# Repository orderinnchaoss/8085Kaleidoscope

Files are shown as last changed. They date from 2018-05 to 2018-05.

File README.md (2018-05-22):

# 8085Kaleidoscope Under Professor D.V.Gadre
This contains files 8085 
Includes
1)Schematics and BoardFiles
2)Main Code(Text,Hex,Bin)
3)Report
4)Program Flowchart

Can be reproduced with permission, by the contacts under

Made by 
 Priyanshu Pandey 130/EC/15 - 95608-59659 - priyanshupandey7997@gmail.com / priyanshup.ec@nsit.net.in
 Nishant Arora 110/EC/15 - 78387-67240 - arora.nishant97@gmail.com

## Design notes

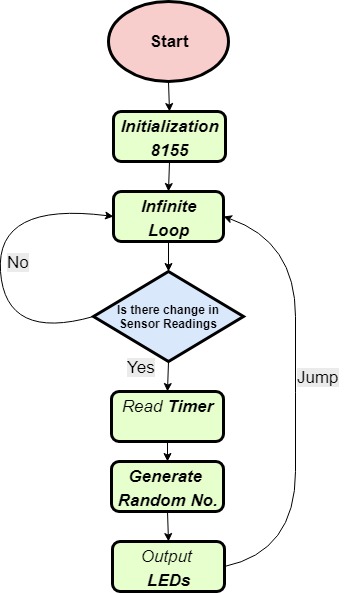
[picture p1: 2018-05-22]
Codeflow.jpg

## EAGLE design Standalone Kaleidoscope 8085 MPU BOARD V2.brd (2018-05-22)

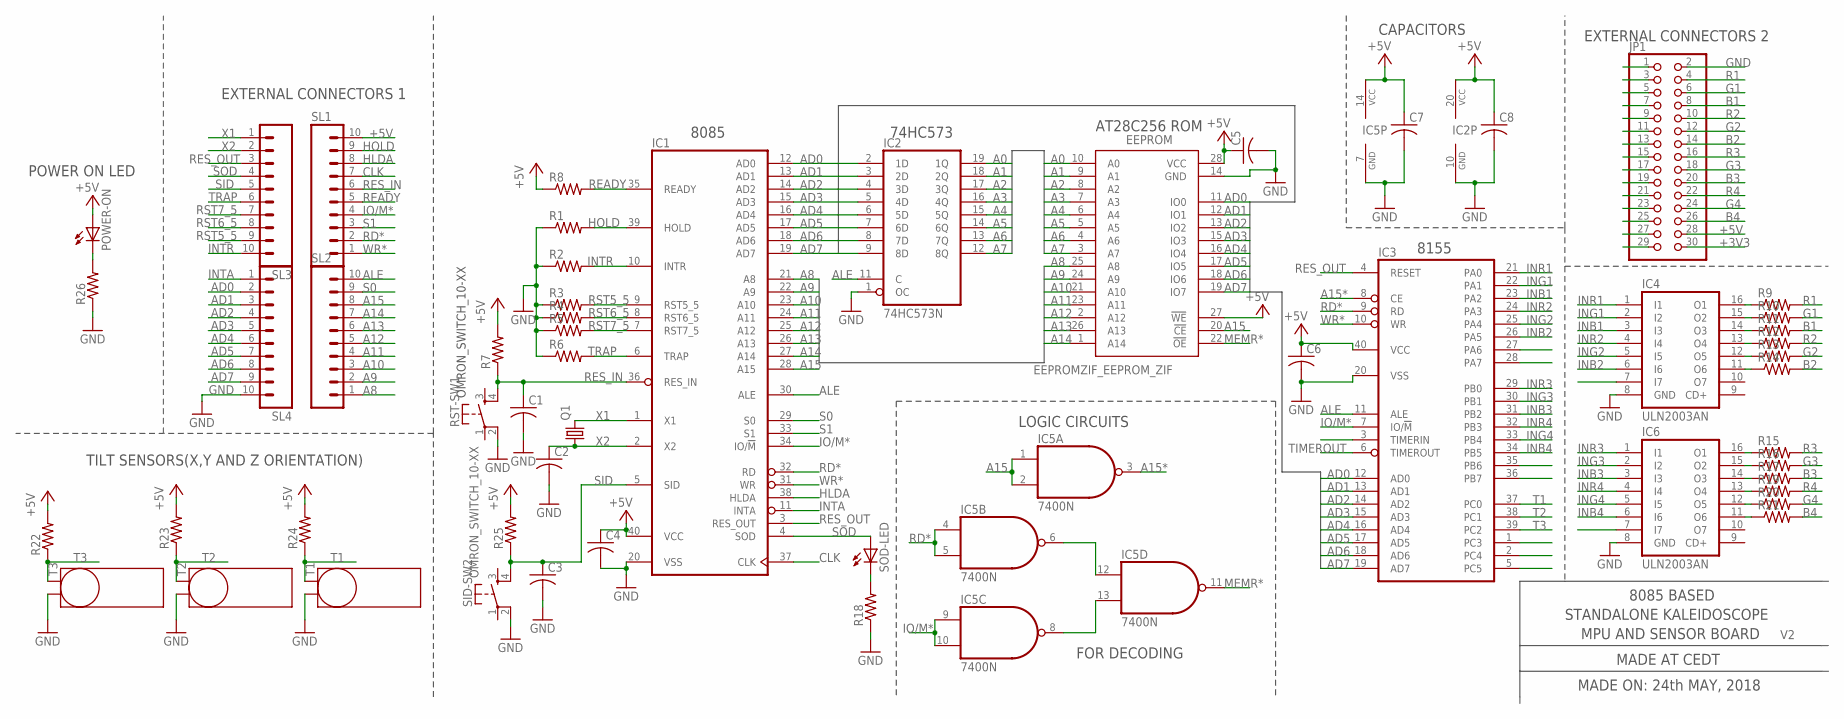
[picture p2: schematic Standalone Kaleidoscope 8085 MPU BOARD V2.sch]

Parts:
C1, C2, C3, C4, C5, C6: C-USC0805K; C0805K
C7, C8: C-USC0805; C0805
EEPROM: EEPROMZIF_EEPROM_ZIF; EEPROMZIF_DIL28-6-ZIF_SOCKET
IC1: 8085; DIL40
IC2: 74HC573N; DIL20
IC3: 8155; DIL40
IC4, IC6: ULN2003AN; DIL16
IC5: 7400N; DIL14
JP1: PINHD-2X15; 2X15
POWER-ON: LEDCHIP-LED0805; CHIP-LED0805
Q1: CEDT_JANUARY_2015_V5_A_CRYSTALHC49US; CEDT_JANUARY_2015_V5_A_HC49US
R1, R2, R3, R4, R5, R6, R7, R8, R9, R10, R11, R12, R13, R14, R15, R16, R17, R18, R19, R20, R21, R22, R23, R24, R25, R26: R-US_R0805; R0805
RST-SW1: OMRON_SWITCH_10-XX; B3F-10XX
SID-SW2: OMRON_SWITCH_10-XX; B3F-10XX
SL1, SL2, SL3, SL4: CON-AMP-QUICK_M10; CON-AMP-QUICK_10P
SOD-LED: LEDCHIP-LED0805; CHIP-LED0805
T1, T2, T3: TILTSENSORE2.5-7; TILTSENSOR

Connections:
+3V3: JP1.29, JP1.30
+5V: C4.1, C5.1, C6.1, C7.1, C8.1, EEPROM.27 (!WE), EEPROM.28 (VCC), IC1.40 (VCC), IC2.20 (VCC), IC3.40 (VCC), IC5.14 (VCC), JP1.27, JP1.28, POWER-ON.A, R7.2, R8.1, R22.2, R23.2, R24.2, R25.2, SL1.10
A0: EEPROM.10 (A0), IC2.19 (1Q)
A1: EEPROM.9 (A1), IC2.18 (2Q)
A2: EEPROM.8 (A2), IC2.17 (3Q)
A3: EEPROM.7 (A3), IC2.16 (4Q)
A4: EEPROM.6 (A4), IC2.15 (5Q)
A5: EEPROM.5 (A5), IC2.14 (6Q)
A6: EEPROM.4 (A6), IC2.13 (7Q)
A7: EEPROM.3 (A7), IC2.12 (8Q)
A8: EEPROM.25 (A8), IC1.21 (A8), SL2.1
A9: EEPROM.24 (A9), IC1.22 (A9), SL2.2
A10: EEPROM.21 (A10), IC1.23 (A10), SL2.3
A11: EEPROM.23 (A11), IC1.24 (A11), SL2.4
A12: EEPROM.2 (A12), IC1.25 (A12), SL2.5
A13: EEPROM.26 (A13), IC1.26 (A13), SL2.6
A14: EEPROM.1 (A14), IC1.27 (A14), SL2.7
A15: EEPROM.20 (!CE), IC1.28 (A15), IC5.1 (I0), IC5.2 (I1), SL2.8
A15*: IC3.8 (CE), IC5.3 (O)
AD0: EEPROM.11 (IO0), IC1.12 (AD0), IC2.2 (1D), IC3.12 (AD0), SL4.2
AD1: EEPROM.12 (IO1), IC1.13 (AD1), IC2.3 (2D), IC3.13 (AD1), SL4.3
AD2: EEPROM.13 (IO2), IC1.14 (AD2), IC2.4 (3D), IC3.14 (AD2), SL4.4
AD3: EEPROM.15 (IO3), IC1.15 (AD3), IC2.5 (4D), IC3.15 (AD3), SL4.5
AD4: EEPROM.16 (IO4), IC1.16 (AD4), IC2.6 (5D), IC3.16 (AD4), SL4.6
AD5: EEPROM.17 (IO5), IC1.17 (AD5), IC2.7 (6D), IC3.17 (AD5), SL4.7
AD6: EEPROM.18 (IO6), IC1.18 (AD6), IC2.8 (7D), IC3.18 (AD6), SL4.8
AD7: EEPROM.19 (IO7), IC1.19 (AD7), IC2.9 (8D), IC3.19 (AD7), SL4.9
ALE: IC1.30 (ALE), IC2.11 (C), IC3.11 (ALE), SL2.10
B1: JP1.7, JP1.8, R11.2
B2: JP1.13, JP1.14, R14.2
B3: JP1.19, JP1.20, R17.2
B4: JP1.25, JP1.26, R21.2
CLK: IC1.37 (CLK), SL1.7
G1: JP1.5, JP1.6, R10.2
G2: JP1.11, JP1.12, R13.2
G3: JP1.17, JP1.18, R16.2
G4: JP1.23, JP1.24, R20.2
GND: C1.2, C2.2, C3.2, C4.2, C5.2, C6.2, C7.2, C8.2, EEPROM.14 (GND), IC1.20 (VSS), IC2.1 (OC), IC2.10 (GND), IC3.20 (VSS), IC4.8 (GND), IC5.7 (GND), IC6.8 (GND), JP1.1, JP1.2, R1.1, R2.1, R3.1, R4.1, R5.1, R6.1, R18.1, R26.1, RST-SW1.2 (P1), SID-SW2.2 (P1), SL4.10, T1.-, T2.-, T3.-
HLDA: IC1.38 (HLDA), SL1.8
HOLD: IC1.39 (HOLD), R1.2, SL1.9
INB1: IC3.23 (PA2), IC4.3 (I3)
INB2: IC3.26 (PA5), IC4.6 (I6)
INB3: IC3.31 (PB2), IC6.3 (I3)
INB4: IC3.34 (PB5), IC6.6 (I6)
ING1: IC3.22 (PA1), IC4.2 (I2)
ING2: IC3.25 (PA4), IC4.5 (I5)
ING3: IC3.30 (PB1), IC6.2 (I2)
ING4: IC3.33 (PB4), IC6.5 (I5)
INR1: IC3.21 (PA0), IC4.1 (I1)
INR2: IC3.24 (PA3), IC4.4 (I4)
INR3: IC3.29 (PB0), IC6.1 (I1)
INR4: IC3.32 (PB3), IC6.4 (I4)
INTA: IC1.11 (INTA), SL4.1
INTR: IC1.10 (INTR), R2.2, SL3.10
IO/M*: IC1.34 (IO/!M), IC3.7 (IO/!M), IC5.9 (I0), IC5.10 (I1), SL1.4
MEMR*: EEPROM.22 (!OE), IC5.11 (O)
unnamed: POWER-ON.C, R26.2
unnamed: IC4.16 (O1), R9.1
unnamed: IC4.15 (O2), R10.1
unnamed: IC4.14 (O3), R11.1
unnamed: IC5.6 (O), IC5.12 (I0)
unnamed: IC5.8 (O), IC5.13 (I1)
unnamed: IC4.13 (O4), R12.1
unnamed: IC4.12 (O5), R13.1
unnamed: IC4.11 (O6), R14.1
unnamed: IC6.11 (O6), R21.1
unnamed: IC6.12 (O5), R20.1
unnamed: IC6.13 (O4), R19.1
unnamed: IC6.14 (O3), R17.1
unnamed: IC6.15 (O2), R16.1
unnamed: R18.2, SOD-LED.C
unnamed: IC6.16 (O1), R15.1
R1: JP1.3, JP1.4, R9.2
R2: JP1.9, JP1.10, R12.2
R3: JP1.15, JP1.16, R15.2
R4: JP1.21, JP1.22, R19.2
RD*: IC1.32 (RD), IC3.9 (RD), IC5.4 (I0), IC5.5 (I1), SL1.2
READY: IC1.35 (READY), R8.2, SL1.5
RES_IN: C1.1, IC1.36 (RES_IN), R7.1, RST-SW1.4 (S1), SL1.6
RES_OUT: IC1.3 (RES_OUT), IC3.4 (RESET), SL3.3
RST5_5: IC1.9 (RST5_5), R3.2, SL3.9
RST6_5: IC1.8 (RST6_5), R4.2, SL3.8
RST7_5: IC1.7 (RST7_5), R5.2, SL3.7
S0: IC1.29 (S0), SL2.9
S1: IC1.33 (S1), SL1.3
SID: C3.1, IC1.5 (SID), R25.1, SID-SW2.4 (S1), SL3.5
SOD: IC1.4 (SOD), SL3.4, SOD-LED.A
T1: IC3.37 (PC0), R24.1, T1.+
T2: IC3.38 (PC1), R23.1, T2.+
T3: IC3.39 (PC2), R22.1, T3.+
TIMEROUT: IC3.6 (TIMEROUT)
TRAP: IC1.6 (TRAP), R6.2, SL3.6
WR*: IC1.31 (WR), IC3.10 (WR), SL1.1
X1: IC1.1 (X1), Q1.2, SL3.1
X2: C2.1, IC1.2 (X2), Q1.1, SL3.2

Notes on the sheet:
TILT SENSORS(X,Y AND Z ORIENTATION)
8085
74HC573
AT28C256 ROM
CAPACITORS
8155
EXTERNAL CONNECTORS 2
EXTERNAL CONNECTORS 1
LOGIC CIRCUITS
POWER ON LED
8085 BASED
STANDALONE KALEIDOSCOPE
MADE AT CEDT
MPU AND SENSOR BOARD
MADE ON: 24th MAY, 2018
FOR DECODING

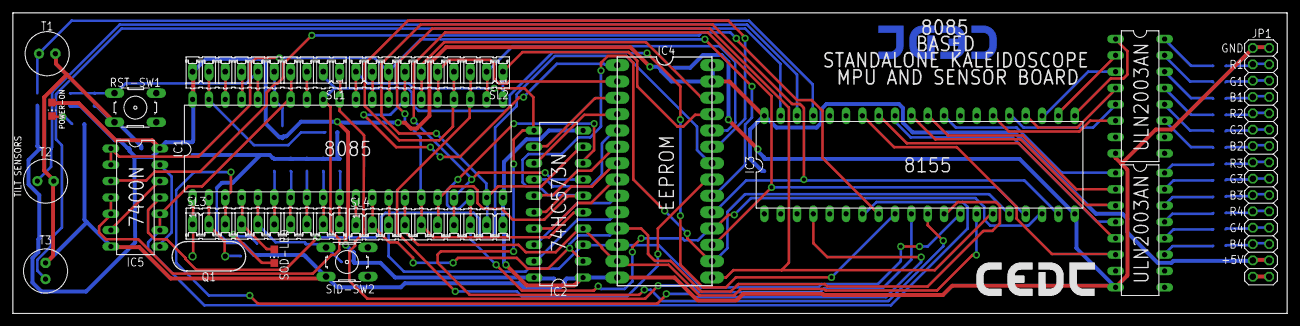
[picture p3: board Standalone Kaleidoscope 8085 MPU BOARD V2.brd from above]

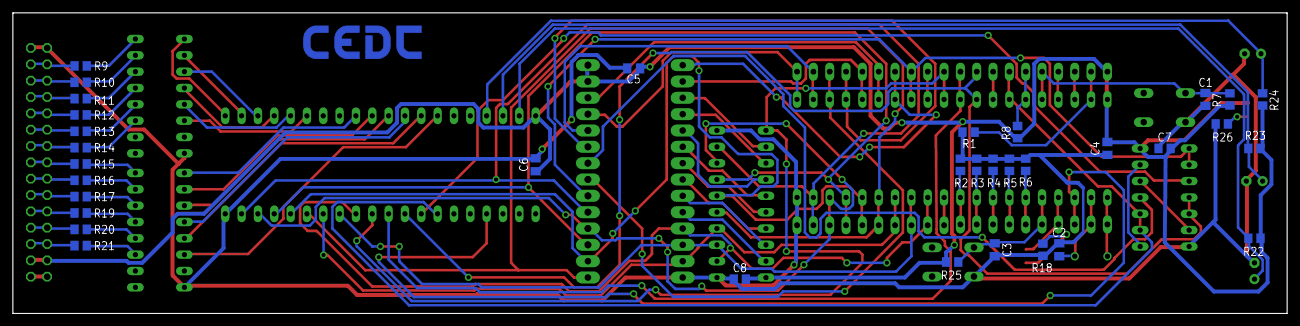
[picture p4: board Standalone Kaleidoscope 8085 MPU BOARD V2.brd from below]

Board: 2 copper layers, 198.1 x 46.7 mm, 56 parts (34 on the bottom side), 94 nets.

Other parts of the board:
U$1: LOGO-CEDT-BOT-18MM
U$4: LOGO-CEDT-SILK-18MM

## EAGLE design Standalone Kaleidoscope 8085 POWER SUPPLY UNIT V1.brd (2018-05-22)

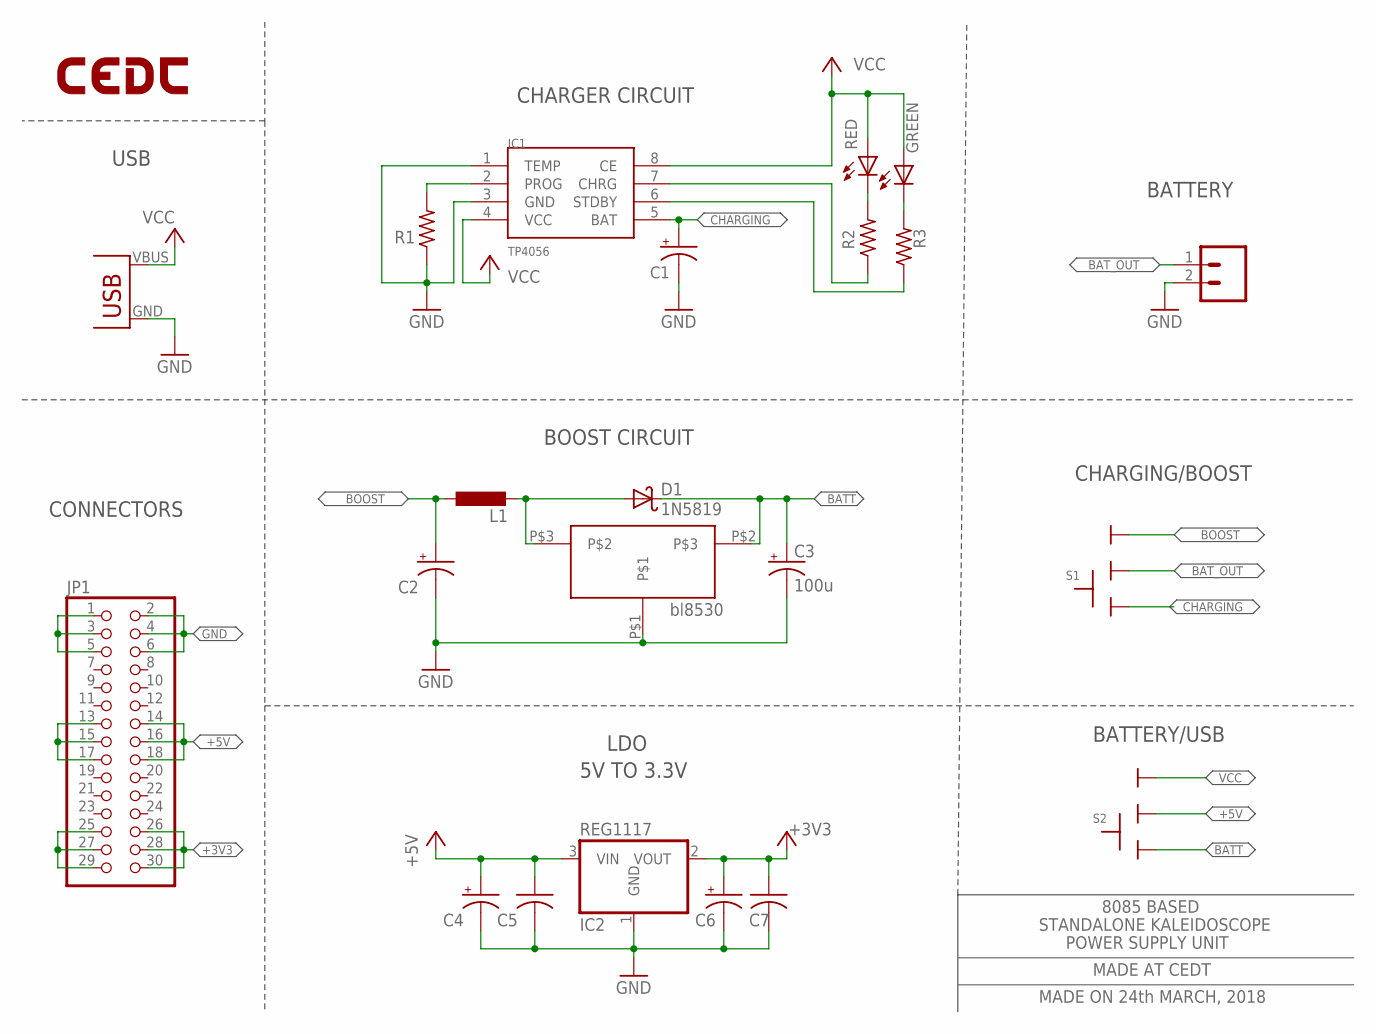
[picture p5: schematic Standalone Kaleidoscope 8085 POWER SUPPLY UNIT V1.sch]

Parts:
BATTERY: M02; 02P
BL8530: BL8530_5V
C1, C2, C4, C6: 10u; C/6032-28R
C3: 100u; C/6032-28R
C5, C7: 0.1u; C0805
D1: 1N5819; DO41-10
GREEN: LED3MM
IC1: TP4056; SOP-8
IC2: REG1117; SOT223
JP1: PINHD-2X15; 2X15
L1: 47uH; L4532P
LOGO1: LOGO-CEDTBOT-18MM; LOGO-CEDT-BOT-18MM
R1: RESISTOR0805; R0805
R2, R3: 470; R0805
RED: LED3MM
S1, S2: SLIDESWITCH-BIG; BIGSWITCH
U$1: USB(POWER)

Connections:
+3V3: C6.+, C7.1, IC2.2 (VOUT), JP1.25, JP1.26, JP1.27, JP1.28, JP1.29, JP1.30
+5V: C4.+, C5.1, IC2.3 (VIN), JP1.13, JP1.14, JP1.15, JP1.16, JP1.17, JP1.18, S2.2
BATT: BL8530.P$2, C3.+, D1.C, S2.1
BAT_OUT: BATTERY.1, S1.2
BOOST: C2.+, L1.1, S1.3
CHARGING: C1.+, IC1.5 (BAT), S1.1
GND: BATTERY.2, BL8530.P$1, C1.-, C2.-, C3.-, C4.-, C5.2, C6.-, C7.2, IC1.1 (TEMP), IC1.3 (GND), IC2.1 (GND), JP1.1, JP1.2, JP1.3, JP1.4, JP1.5, JP1.6, R1.1, U$1.GND
unnamed: IC1.2 (PROG), R1.2
unnamed: R2.2, RED.K (C)
unnamed: IC1.6 (STDBY), R3.1
unnamed: IC1.7 (CHRG), R2.1
unnamed: BL8530.P$3, D1.A, L1.2
unnamed: GREEN.K (C), R3.2
VCC: GREEN.A, IC1.4 (VCC), IC1.8 (CE), RED.A, S2.3, U$1.VBUS (VCC)

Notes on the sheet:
CHARGER CIRCUIT
BOOST CIRCUIT
LDO
bl8530
CONNECTORS
CHARGING/BOOST
USB
5V TO 3.3V
BATTERY/USB
8085 BASED
STANDALONE KALEIDOSCOPE
POWER SUPPLY UNIT
MADE AT CEDT
MADE ON 24th MARCH, 2018

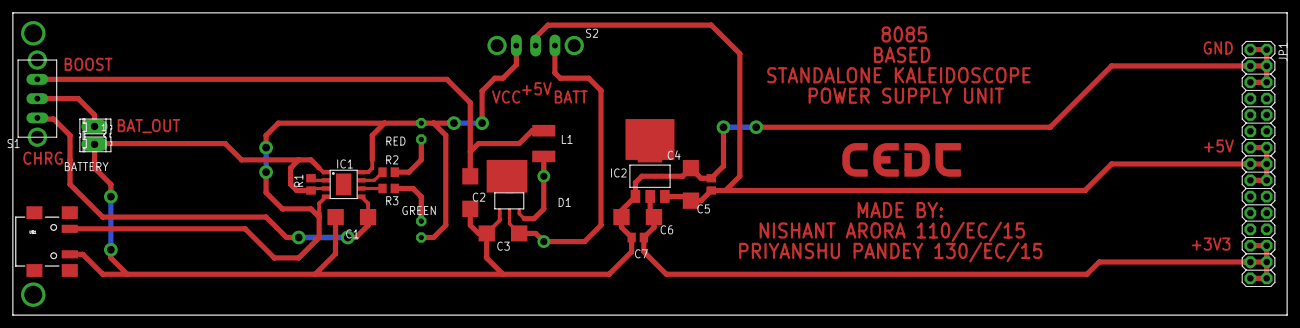
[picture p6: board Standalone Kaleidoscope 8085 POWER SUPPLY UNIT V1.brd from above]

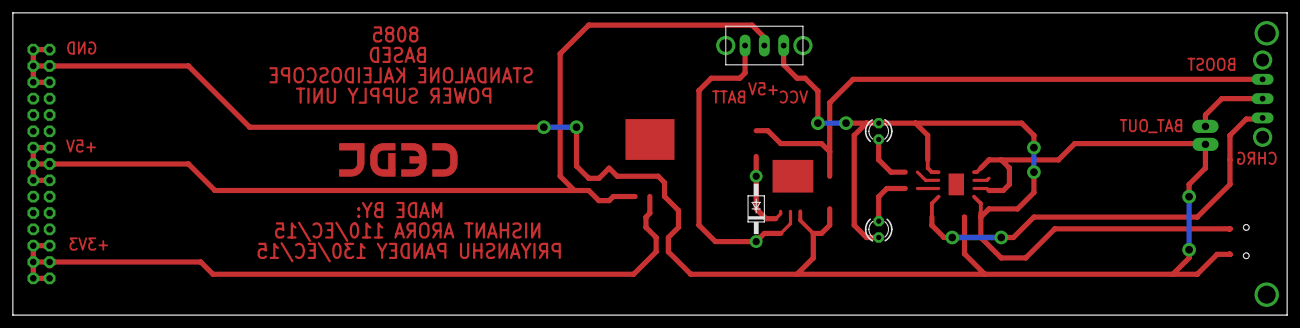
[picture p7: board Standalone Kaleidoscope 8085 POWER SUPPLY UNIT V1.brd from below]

Board: 2 copper layers, 198.1 x 47.0 mm, 23 parts (5 on the bottom side), 14 nets.

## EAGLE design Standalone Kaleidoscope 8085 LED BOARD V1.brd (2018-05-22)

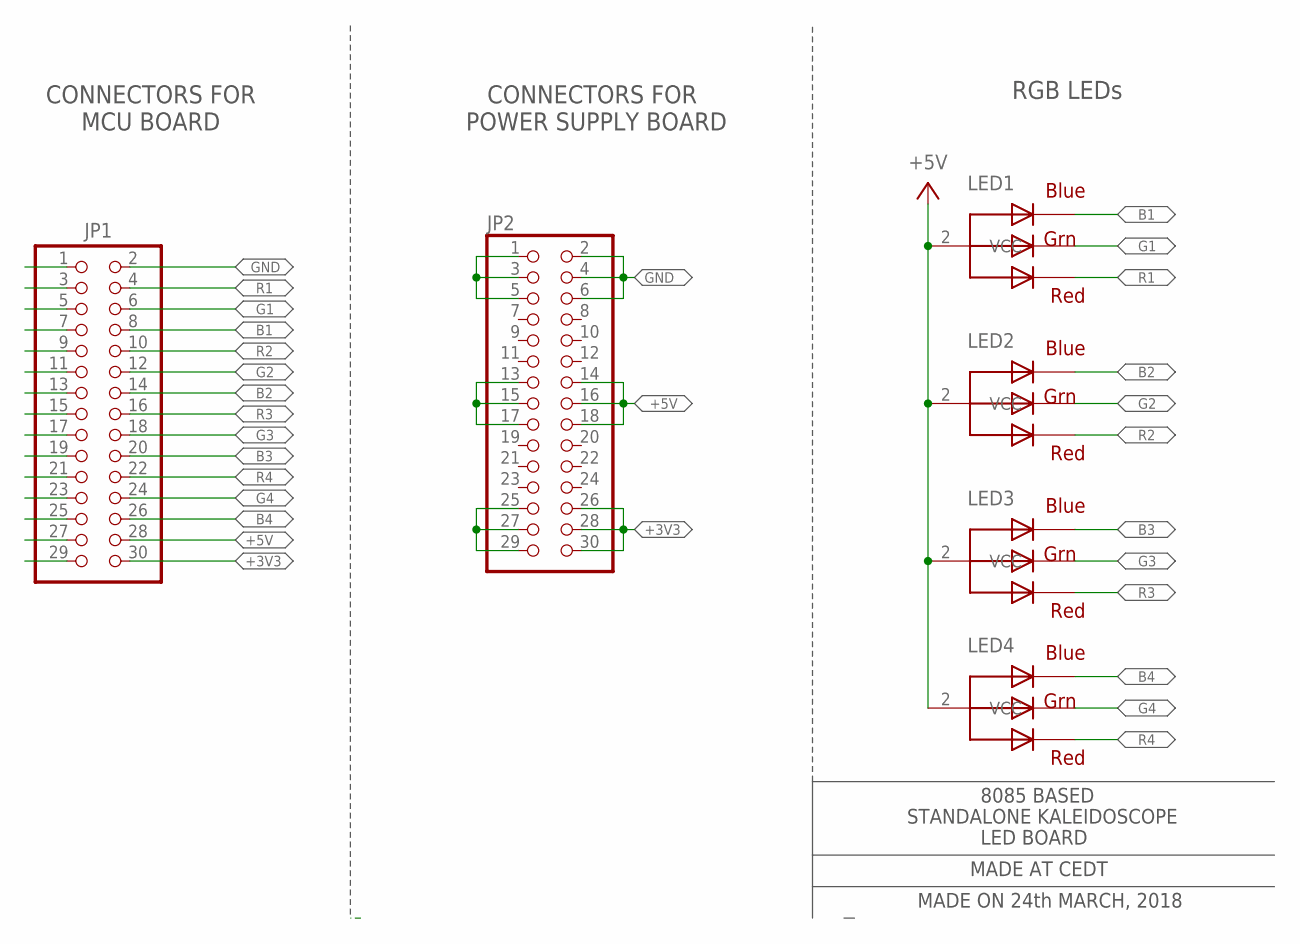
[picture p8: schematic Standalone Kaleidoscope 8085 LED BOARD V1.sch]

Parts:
JP1, JP2: PINHD-2X15; 2X15
LED1, LED2, LED3, LED4: RGBLED_CA; LED5MMRGB

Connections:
+3V3: JP1.29, JP1.30, JP2.25, JP2.26, JP2.27, JP2.28, JP2.29, JP2.30
+5V: JP1.27, JP1.28, JP2.13, JP2.14, JP2.15, JP2.16, JP2.17, JP2.18, LED1.2 (VCC), LED2.2 (VCC), LED3.2 (VCC), LED4.2 (VCC)
B1: JP1.7, JP1.8, LED1.4 (BLUE)
B2: JP1.13, JP1.14, LED2.4 (BLUE)
B3: JP1.19, JP1.20, LED3.4 (BLUE)
B4: JP1.25, JP1.26, LED4.4 (BLUE)
G1: JP1.5, JP1.6, LED1.3 (GREEN)
G2: JP1.11, JP1.12, LED2.3 (GREEN)
G3: JP1.17, JP1.18, LED3.3 (GREEN)
G4: JP1.23, JP1.24, LED4.3 (GREEN)
GND: JP1.1, JP1.2, JP2.1, JP2.2, JP2.3, JP2.4, JP2.5, JP2.6
R1: JP1.3, JP1.4, LED1.1 (RED)
R2: JP1.9, JP1.10, LED2.1 (RED)
R3: JP1.15, JP1.16, LED3.1 (RED)
R4: JP1.21, JP1.22, LED4.1 (RED)

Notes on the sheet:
CONNECTORS FOR MCU BOARD
CONNECTORS FOR POWER SUPPLY BOARD
RGB LEDs
8085 BASED
STANDALONE KALEIDOSCOPE
LED BOARD
MADE AT CEDT
MADE ON 24th MARCH, 2018

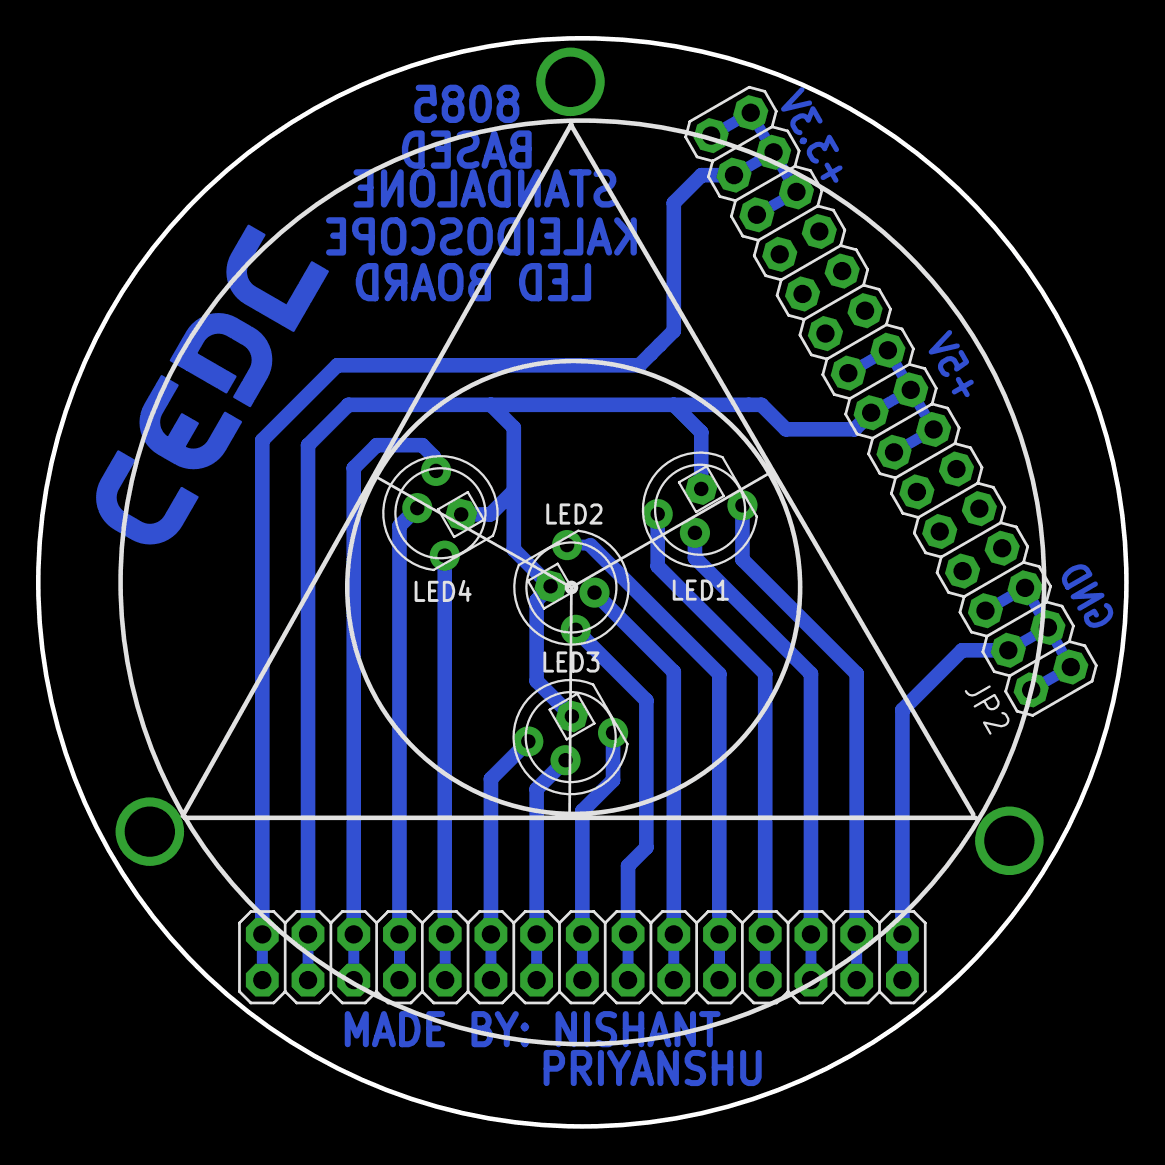
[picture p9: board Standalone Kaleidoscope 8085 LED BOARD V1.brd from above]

Board: 2 copper layers, 60.5 x 60.5 mm, 7 parts (0 on the bottom side), 15 nets.

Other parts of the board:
U$1: LOGO-CEDT-BOT-18MM
